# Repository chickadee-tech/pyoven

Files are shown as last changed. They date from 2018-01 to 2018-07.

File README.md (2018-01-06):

# Chickadee Tech pyoven #
This is a replacement control board for a [Breville 450XL](https://remanufactured.brevilleusa.com/collections/ovens/products/mini-smart-oven-rm-bov450xl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),
their smallest toaster oven. Its meant to enable programming the oven using CircuitPython. It can
then be used for food or reflowing PCBs but do not mix the two in the same oven.

DO NOT leave the oven unattended!

## Contributing ##
Please note that this project is released with a [Contributor Code of Conduct](CODE_OF_CONDUCT.md). By participating in this project you agree to abide by its terms.

### Setup ###
Components and footprints for PCB parts are not included in this repository. Instead, checkout the [chickadee-tech/kicad-libs](https://github.com/chickadee-tech/kicad-libs) repository in the same directory that this repository is checked out in. All part definitions should be relative so that they will load correctly.

### Pull requests ###
For fixes please submit a pull request to the original repository.

### Derivatives ###
If developing your own version of the spacer board please remove all Chickadee Tech trademarks and follow the [CC-BY license](LICENSE). While not required, please consider open sourcing your modifications so others can learn from your improvements.

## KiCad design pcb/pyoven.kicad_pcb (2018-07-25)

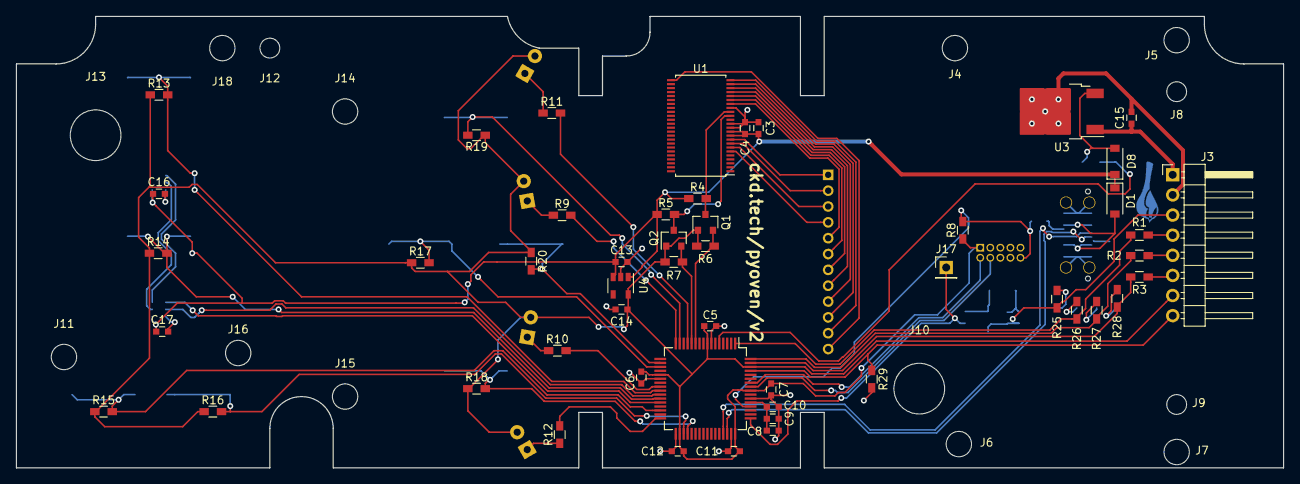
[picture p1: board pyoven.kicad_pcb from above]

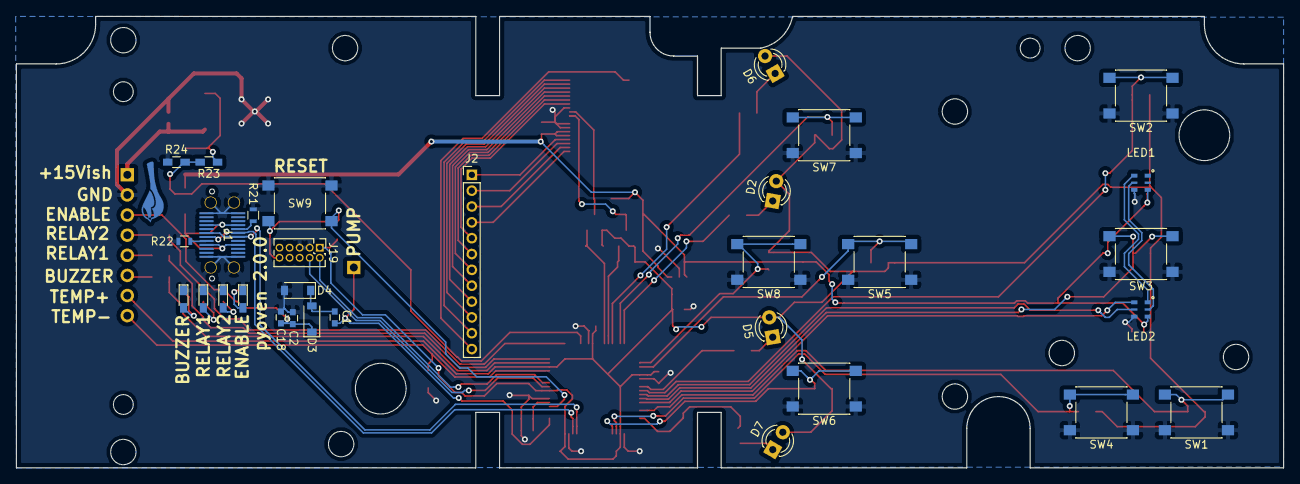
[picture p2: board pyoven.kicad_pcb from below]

Board: 2 copper layers, 160.0 x 57.0 mm, 95 parts (31 on the bottom side), 65 nets.

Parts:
C1, C3, C4, C5, C6, C7, C10, C11, C12, C16, C17: 0.1uF; C_0603
C2, C8, C18: 10uF; C_0603
C9, C13, C14, C15: 1uF; C_0603
D1, D3, D4, D8: MBR120; D_SOD-123
D2, D5, D6, D7: LED_Small_ALT; LED_D3.0mm
D9, D10, D11, D12: SMD; LED_0603_HandSoldering
J1: USB_C_Receptacle; DX07S024WJ3-OSHPARK-HS
J2: Conn_01x12; Pin_Header_Straight_1x12_Pitch2.00mm
J3: Conn_01x08; Pin_Header_Angled_1x08_Pitch2.54mm
J4, J5, J6, J7, J11, J14, J15, J16, J18: Conn_01x01; MountingHole_3.2mm_M3
J8, J9, J12: Conn_01x01; MountingHole_2.5mm
J10, J13: Conn_01x01; MountingHole_6.4mm_M6
J17: Conn_01x01; Pin_Header_Straight_1x01_Pitch2.54mm
J19: Conn_02x05_Odd_Even; Pin_Header_Straight_2x05_Pitch1.27mm
LED1, LED2: APA102; APA102-2020
Q1, Q2: BSS138; SOT-23
R1, R2, R3, R24: 3.3k; R_0603_HandSoldering
R4, R5, R6, R7: 4.7k; R_0603_HandSoldering
R8, R13, R14, R15, R16, R17, R18, R19, R20, R29: 10k; R_0603_HandSoldering
R9, R10, R11, R12, R25, R26, R27, R28: 1k; R_0603_HandSoldering
R21, R22: 5.1k; R_0603
R23: 2.2k; R_0603_HandSoldering
SW1: Frozen; SW_SPST_PTS645
SW2: More; SW_SPST_PTS645
SW3: Start; SW_SPST_PTS645
SW4: C/F; SW_SPST_PTS645
SW5: Dec; SW_SPST_PTS645
SW6: Temp; SW_SPST_PTS645
SW7: Time; SW_SPST_PTS645
SW8: Inc; SW_SPST_PTS645
SW9: Reset; SW_SPST_PTS645
U1: PCF8551ATT; TSSOP-48_6.1x12.5mm_Pitch0.5mm
U2: SAMD51J; TQFP-64_10x10mm_Pitch0.5mm
U3: L7805; TO-252-2
U4: AP2204K-1.5; SOT-23-5

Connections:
+3V3: C5.2, C6.1, C7.2, C11.2, C12.2, C14.1, D2.2, D5.2, D6.2, D7.2, J3.7, J19.1, Q1.1, Q2.1, R6.1, R7.1, R8.1, R13.1, R14.1, R15.1, R16.1, R17.1, R18.1, R19.1, R20.1, U2.8, U2.21, U2.34, U2.48, U2.56, U2.62, U4.5
+5V: C3.1, C4.1, C13.1, C16.1, C17.1, D1.1, D8.1, LED1.3, LED2.3, R4.1, R5.1, U1.10, U1.11, U4.1, U4.3
+VDC: C15.1, J3.1, U3.1
/BUZZER: R3.2, R28.1, U2.63
/CI: LED2.5, U2.26
/CO: LED1.5, LED2.2
/COM0: J2.4, U1.6
/COM1: J2.3, U1.7
/COM2: J2.2, U1.8
/COM3: J2.1, U1.9
/D+: J1.A6, J1.B6, U2.46
/D-: J1.A7, J1.B7, U2.45
/DEC: R17.2, SW5.2, U2.19
/DI: LED2.6, U2.28
/DO: LED1.6, LED2.1
/ENABLE: C2.1, C18.1, D3.1, J3.3, R25.1
/FAR_LEFT_LED: R12.2, U2.32
/FAR_RIGHT_LED: R11.2, U2.13
/FROZEN: R15.2, SW1.2, U2.30
/INC: R20.2, SW8.2, U2.18
/LEFT_LED: R10.2, U2.24
/MORE: R13.2, SW2.2, U2.25
/PUMP: C1.2, J17.1, U2.49
/RELAY1: R2.2, R27.1, U2.64
/RELAY2: R1.2, R26.1, U2.1
/RIGHT_LED: R9.2, U2.16
/SCL_3V: Q2.2, R7.2, U2.12
/SCL_5V: Q2.3, R5.2, U1.15
/SDA_3V: Q1.2, R6.2, U2.11
/SDA_5V: Q1.3, R4.2, U1.16
/SEG0: J2.5, U1.18
/SEG1: J2.6, U1.19
/SEG2: J2.7, U1.20
/SEG3: J2.8, U1.21
/SEG4: J2.9, U1.22
/SEG5: J2.10, U1.23
/SEG6: J2.11, U1.24
/SEG7: J2.12, U1.25
/START: R14.2, SW3.2, U2.27
/SWDCLK: J19.4, U2.57
/SWDIO: J19.2, U2.58
/TEMP: R18.2, SW6.2, U2.36
/TEMP-: J3.8, R29.1, U2.61
/TIME: R19.2, SW7.2, U2.15
/TOASTER_5V: D8.2, R23.1, U3.3
/UNITS: R16.2, SW4.2, U2.35
/nReset: J19.10, R8.2, SW9.2, U2.52
GNDPWR: C2.2, C3.2, C4.2, C5.1, C6.2, C7.1, C8.2, C9.2, C10.2, C11.1, C12.1, C13.2, C14.2, C15.2, C16.2, C17.2, C18.2, D4.2, D9.1, D10.1, D11.1, D12.1, J1.A1, J1.A12, J1.B1, J1.B12, J1.S1, J3.2, J19.3, J19.5, LED1.4, LED2.4, R21.2, R22.2, R24.2, R29.2, SW1.1, SW2.1, SW3.1, SW4.1, SW5.1, SW6.1, SW7.1, SW8.1, SW9.1, U1.12, U1.13, U1.17, U2.7, U2.22, U2.33, U2.47, U2.54, U3.2, U4.2
unnamed: C1.1, D3.2, D4.1
unnamed: C8.1, C9.1, C10.1, U2.53
unnamed: D1.2, J1.A4, J1.A9, J1.B4, J1.B9
unnamed: D2.1, R9.1
unnamed: D5.1, R10.1
unnamed: D6.1, R11.1
unnamed: D7.1, R12.1
unnamed: D9.2, R25.2
unnamed: D10.2, R26.2
unnamed: D11.2, R27.2
unnamed: D12.2, R28.2
unnamed: J1.A5, R22.1
unnamed: J1.B5, R21.1
unnamed: J3.4, R1.1
unnamed: J3.5, R2.1
unnamed: J3.6, R3.1
unnamed: R23.2, R24.1, U2.5

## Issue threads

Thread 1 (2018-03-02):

SAMD51J symbol not in kicad-libs repository?

adamwolf, 2018-03-02:
I tried to take a look today, and when I downloaded kicad-libs, I only see one component, SAMD21J.  I didn't see any other branches.

Is there somewhere else I can find that symbol?

Thanks!

tannewt, 2018-03-02:
Check again. I hadn't pushed my latest changes to it. Why are you interested in it? There are a couple fixes to the design I haven't done and pushed yet.

adamwolf, 2018-03-03:
Just curious about the schematic, that's all.  Collecting some examples of
SAMD51 stuff.

On Thu, Mar 1, 2018 at 11:45 PM, Scott Shawcroft <notifications@github.com>
wrote:

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

tannewt, 2018-03-05:
Cool cool. The current schematic has 3v3 on vddcore which is wrong. Once I cut that trace it worked just fine.

I saw you do the Mac packaging for Kicad. I really appreciate it! I'm a huge fan of Kicad.

adamwolf, 2018-03-25:
Thanks!

Closed 2018-03-25.

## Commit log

2018-01-06 Initial version. Ordered from OSH Park.
    [pyoven-B.Cu.gbl, pyoven-B.Mask.gbs, pyoven-B.SilkS.gbo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]
2018-07-25 A number of fixes: * lcd pin swap * button location tweak * temp divider resistor * correct regulator footprint
    [pyoven-B.Cu.gbl, pyoven-B.Mask.gbs, pyoven-B.SilkS.gbo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]
